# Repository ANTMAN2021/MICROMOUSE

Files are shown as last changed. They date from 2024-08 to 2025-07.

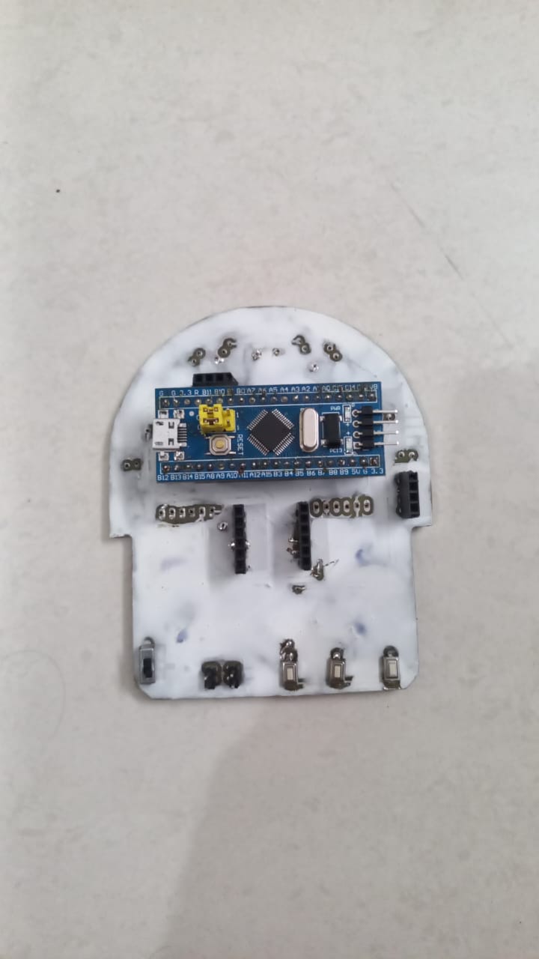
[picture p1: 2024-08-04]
Images/IMG-20240708-WA0024.jpg

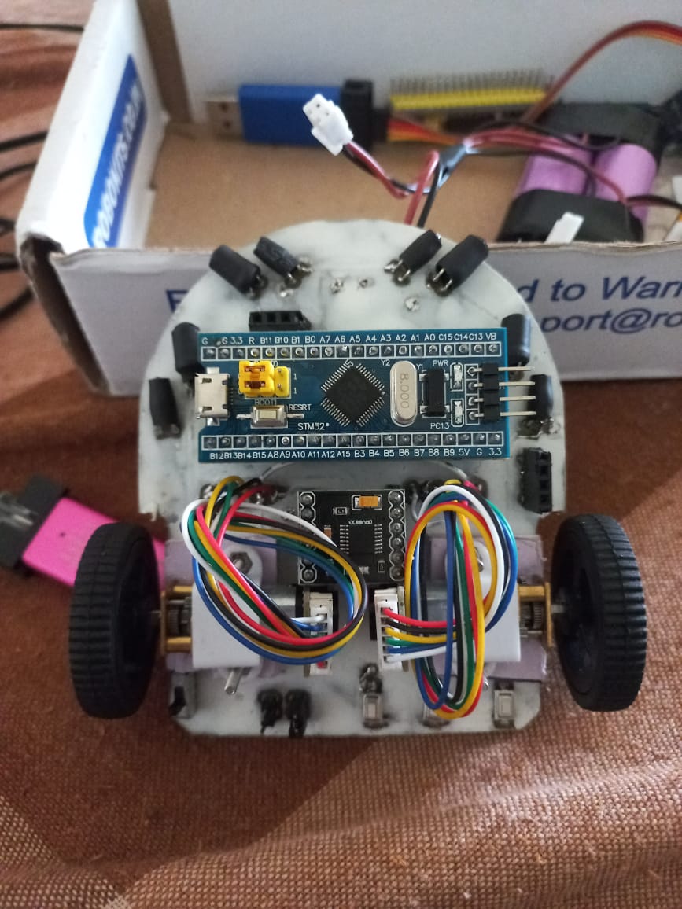
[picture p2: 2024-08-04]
Images/IMG-20240804-WA0022.jpg

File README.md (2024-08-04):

# MICROMOUSE
As a Team Robotics projects, this is a stm32 based micromouse.
There are two pcbs, one based on stm32f103c8t6 and other on stm32f405rgt6.
The assembled bot is on stm32f103 bluepill.
Motor driver used is DRV8833 and sensors are IR sensors.
N20 motors with encoders are used.
Basic running code is given above, shortest path algorithm is in progress.

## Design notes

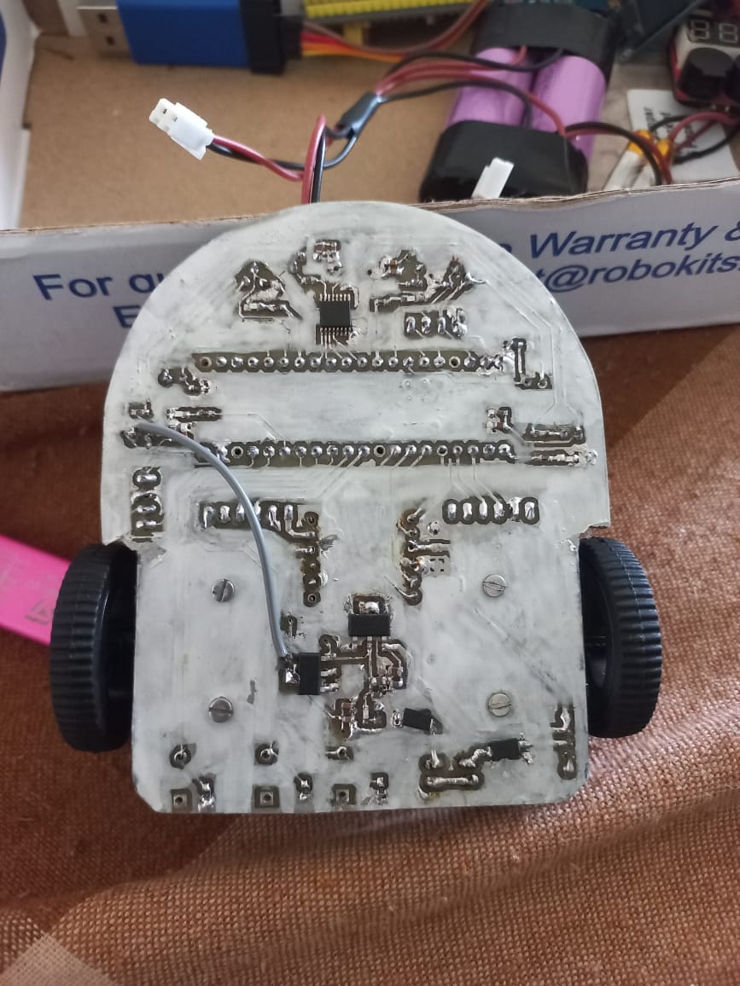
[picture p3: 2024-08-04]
Images/IMG-20240804-WA0023.jpg

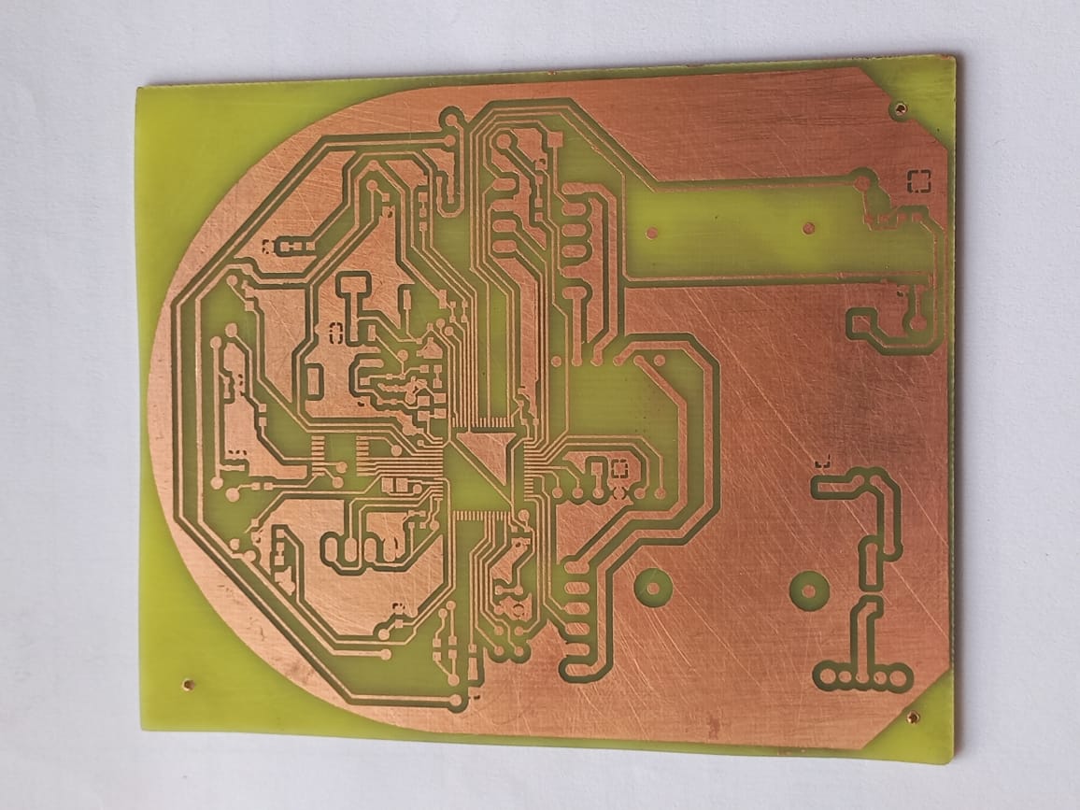
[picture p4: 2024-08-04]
Images/IMG-20240804-WA0025.jpg

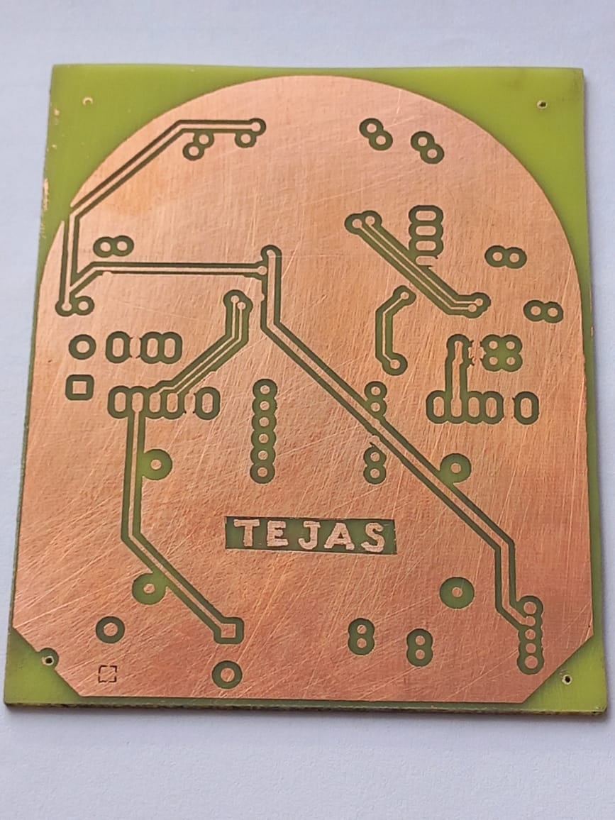
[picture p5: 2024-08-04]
Images/IMG-20240804-WA0026.jpg

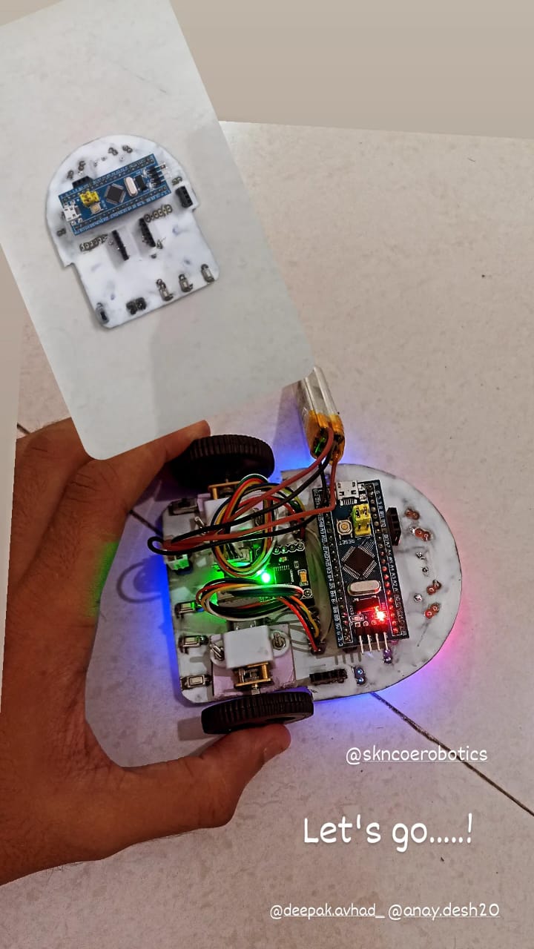
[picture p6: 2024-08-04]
Images/IMG-20240804-WA0024.jpg

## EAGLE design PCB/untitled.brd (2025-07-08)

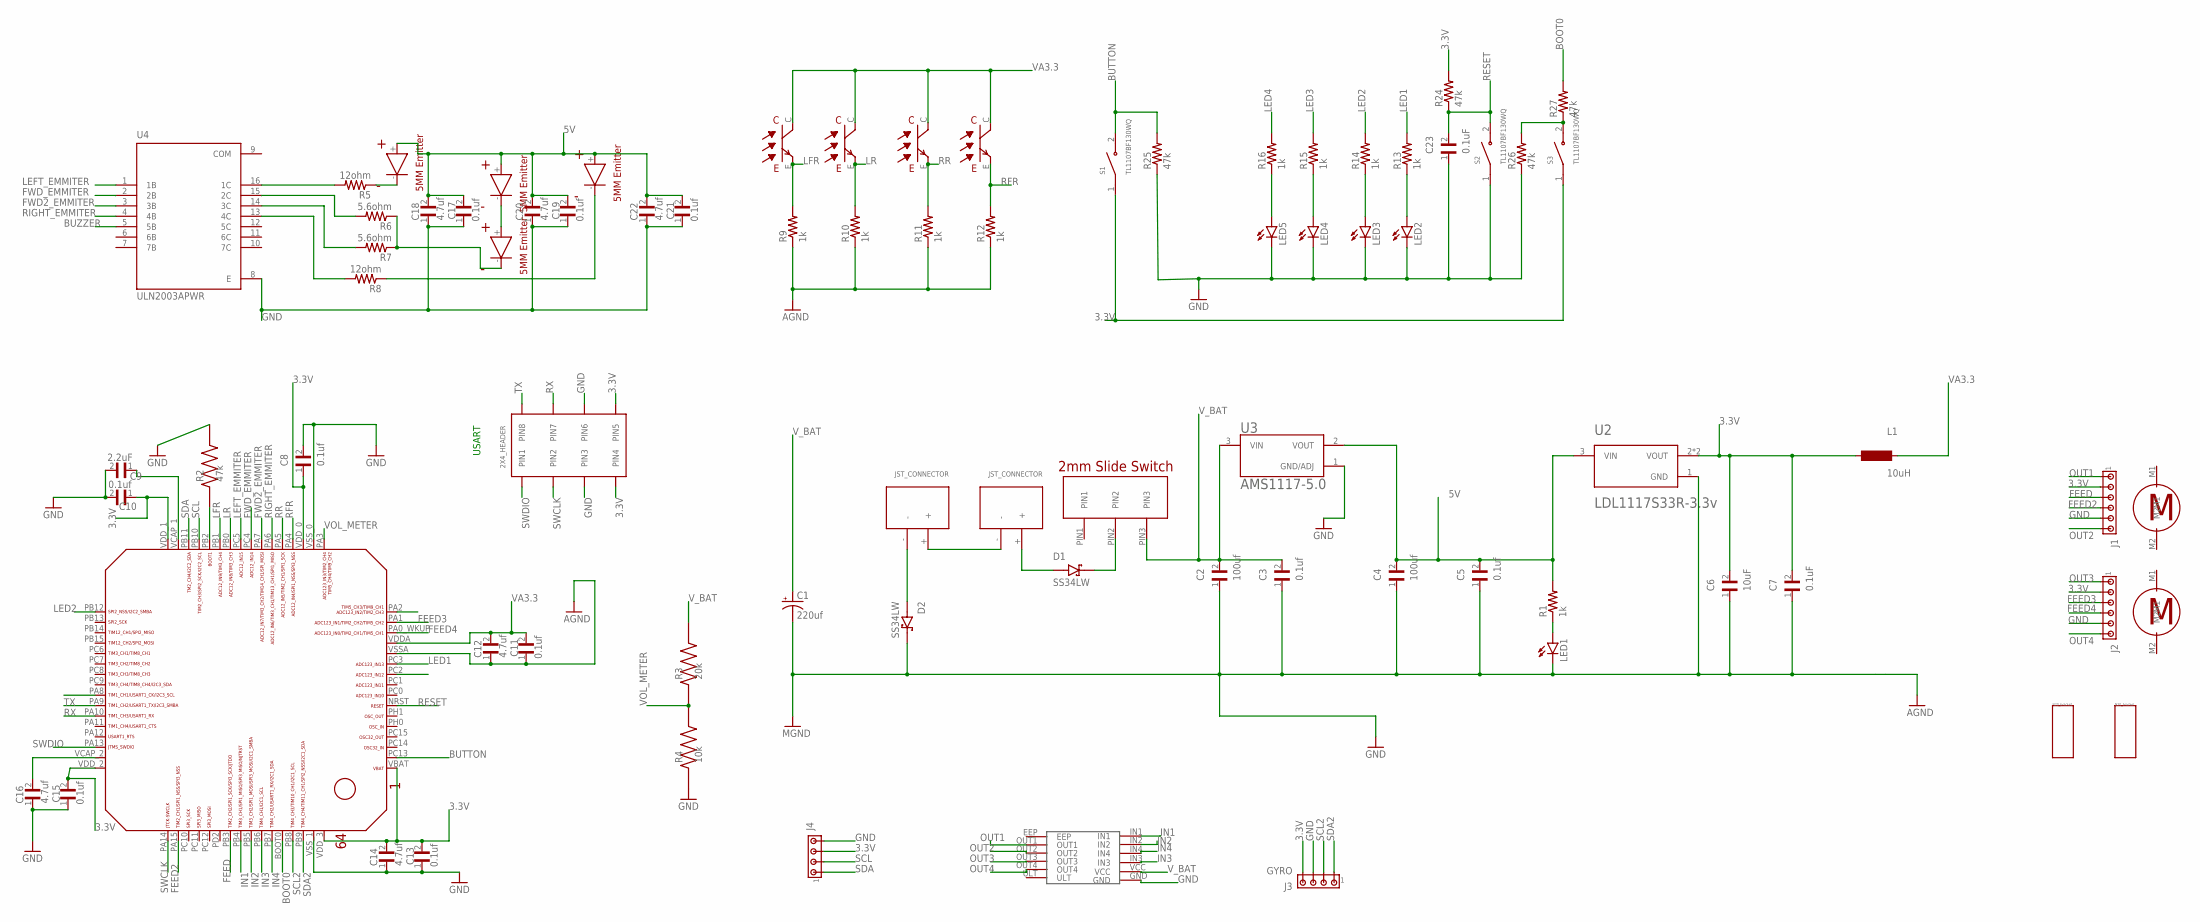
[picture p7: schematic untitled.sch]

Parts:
C1: 220uf; EIA3216
C2, C4: 100uf; CAPC0603X35N
C3, C5, C8, C10, C11, C13, C15, C17, C19, C21: 0.1uf; CAPC0603X35N
C6: 10uF; CAPC0603X35N
C7, C23: 0.1uF; CAPC0603X35N
C9: 2.2uF; CAPC0603X35N
C12, C14, C16, C18, C20, C22: 4.7uf; CAPC0603X35N
D1, D2: SS34LW; SODFL3718X102N
EMMI1: EMITTER
J1, J2: MTA06-100; 10X06MTA
J3: GYRO; 10X04MTA
J4: MTA04-100; 10X04MTA
L1: 10uH; MS42
LED1, LED2, LED3, LED4, LED5: LEDCHIPLED_0805; CHIPLED_0805
R1, R9, R10, R11, R12, R13, R14, R15, R16: 1k; 0603-RES
R2: 47k; RES_ERJU01F3570C
R3: 20k; RES_ERJU01F3570C
R4: 10k; RES_ERJU01F3570C
R5, R8: 12ohm; 0603-RES
R6, R7: 5.6ohm; 0603-RES
R24, R25, R26, R27: 47k; 0603-RES
S1, S2, S3: TL1107BF130WQ; SW_TL1107BF130WQ
STM32F405RGT6: STM32F405/415_LQFP64
U2: LDL1117S33R-3.3v; SOT230P700X180-4N
U3: AMS1117-5.0; SOT229P700X180-4N
U4: ULN2003APWR; SOP65P640X120-16N
U$1, U$4: N20_BRACKET; BRACKER
U$2, U$3: MOTOR_N20
U$5, U$6: JST_CONNECTOR_FEMALE
U$8: 2MMS_SLIDE_SWITCH
U$10: 2X3_HEADER
U$11: DRV8833
U$12, U$16, U$17, U$18: RECEIVER
U$13, U$14, U$15: EMITTER

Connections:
3.3V: C6.2, C7.2, C8.1, C10.1, C13.2, C14.2, C15.2, J1.2, J2.2, J3.4, J4.3, L1.1, R24.2, S1.1, S3.1, STM32F405RGT6.VBAT, STM32F405RGT6.VDD_0, STM32F405RGT6.VDD_1, STM32F405RGT6.VDD_2, STM32F405RGT6.VDD_3, U2.2 (VOUT), U2.4 (VOUT), U$10.PIN4, U$10.PIN5
5V: C4.2, C5.2, C17.2, C18.2, C19.2, C20.2, C21.2, C22.2, EMMI1.+, R1.2, U2.3 (VIN), U3.2 (VOUT), U$13.+, U$15.+
BOOT0: R27.2, STM32F405RGT6.BOOT0
BUTTON: R25.2, S1.2, STM32F405RGT6.PC13
BUZZER: U4.5 (5B)
COM: U4.9 (COM)
FEED: J1.3, STM32F405RGT6.PB3
FEED2: J1.4, STM32F405RGT6.PA15
FEED3: J2.3, STM32F405RGT6.PA1
FEED4: J2.4, STM32F405RGT6.PA0_WKUP (PA0_AKUP)
FWD2_EMMITER: STM32F405RGT6.PA7, U4.3 (3B)
FWD_EMMITER: STM32F405RGT6.PC4, U4.2 (2B)
GND: C1.C (-), C2.1, C3.1, C4.1, C5.1, C6.1, C7.1, C8.2, C9.2, C10.2, C11.1, C12.1, C13.1, C14.1, C15.1, C16.1, C17.1, C18.1, C19.1, C20.1, C21.1, C22.1, C23.1, D2.C (K), J1.5, J2.5, J3.3, J4.4, LED1.C, LED2.C, LED3.C, LED4.C, LED5.C, R2.2, R4.1, R9.1, R10.1, R11.1, R12.1, R25.1, R26.1, S2.1, STM32F405RGT6.VSSA, STM32F405RGT6.VSS_0, STM32F405RGT6.VSS_1, U2.1 (GND), U3.1 (GND/ADJ), U4.8 (E), U$10.PIN3, U$10.PIN6, U$11.GND
IN1: STM32F405RGT6.PB4, U$11.IN1
IN2: STM32F405RGT6.PB5, U$11.IN2
IN3: STM32F405RGT6.PB6, U$11.IN3
IN4: STM32F405RGT6.PB7, U$11.IN4
LED1: R13.2, STM32F405RGT6.PC3
LED2: R14.2, STM32F405RGT6.PB12
LED3: R15.2, STM32F405RGT6.PC2
LED4: R16.2, STM32F405RGT6.PA8
LEFT_EMMITER: STM32F405RGT6.PC5, U4.1 (1B)
LFR: R9.2, STM32F405RGT6.PB1, U$18.E
LR: R10.2, STM32F405RGT6.PB0, U$17.E
unnamed: U$13.-, U$14.+
unnamed: U$5.+, U$6.-
unnamed: R2.1, STM32F405RGT6.PB2
unnamed: D1.C (K), U$8.PIN2
unnamed: R7.2, U4.14 (3C)
unnamed: C9.1, STM32F405RGT6.VCAP_1
unnamed: LED1.A, R1.1
unnamed: C16.2, STM32F405RGT6.VCAP_2
unnamed: LED2.A, R13.1
unnamed: D1.A, U$6.+
unnamed: EMMI1.-, R5.1
unnamed: R5.2, U4.16 (1C)
unnamed: D2.A, U$5.-
unnamed: LED3.A, R14.1
unnamed: R6.2, U4.15 (2C)
unnamed: R6.1, R7.1, U$14.-
unnamed: R8.2, U4.13 (4C)
unnamed: R8.1, U$15.-
unnamed: LED4.A, R15.1
unnamed: R26.2, R27.1, S3.2
unnamed: LED5.A, R16.1
OUT1: J1.1, U$11.OUT1
OUT2: J1.6, U$11.OUT2
OUT3: J2.1, U$11.OUT3
OUT4: J2.6, U$11.OUT4
RESET: C23.2, R24.1, S2.2, STM32F405RGT6.NRST
RFR: R12.2, STM32F405RGT6.PA4, U$12.E
RIGHT_EMMITER: STM32F405RGT6.PA6, U4.4 (4B)
RR: R11.2, STM32F405RGT6.PA5, U$16.E
RX: STM32F405RGT6.PA10, U$10.PIN7
SCL: J4.2, STM32F405RGT6.PB10
SCL2: J3.2, STM32F405RGT6.PB8
SDA: J4.1, STM32F405RGT6.PB11
SDA2: J3.1, STM32F405RGT6.PB9
SWCLK: STM32F405RGT6.PA14, U$10.PIN2
SWDIO: STM32F405RGT6.PA13, U$10.PIN1
TX: STM32F405RGT6.PA9, U$10.PIN8
VA3.3: C11.2, C12.2, L1.2, STM32F405RGT6.VDDA, U$12.C, U$16.C, U$17.C, U$18.C
VOL_METER: R3.1, R4.2, STM32F405RGT6.PA3
V_BAT: C1.A (+), C2.2, C3.2, R3.2, U3.3 (VIN), U$8.PIN3, U$11.VCC

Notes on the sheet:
USART

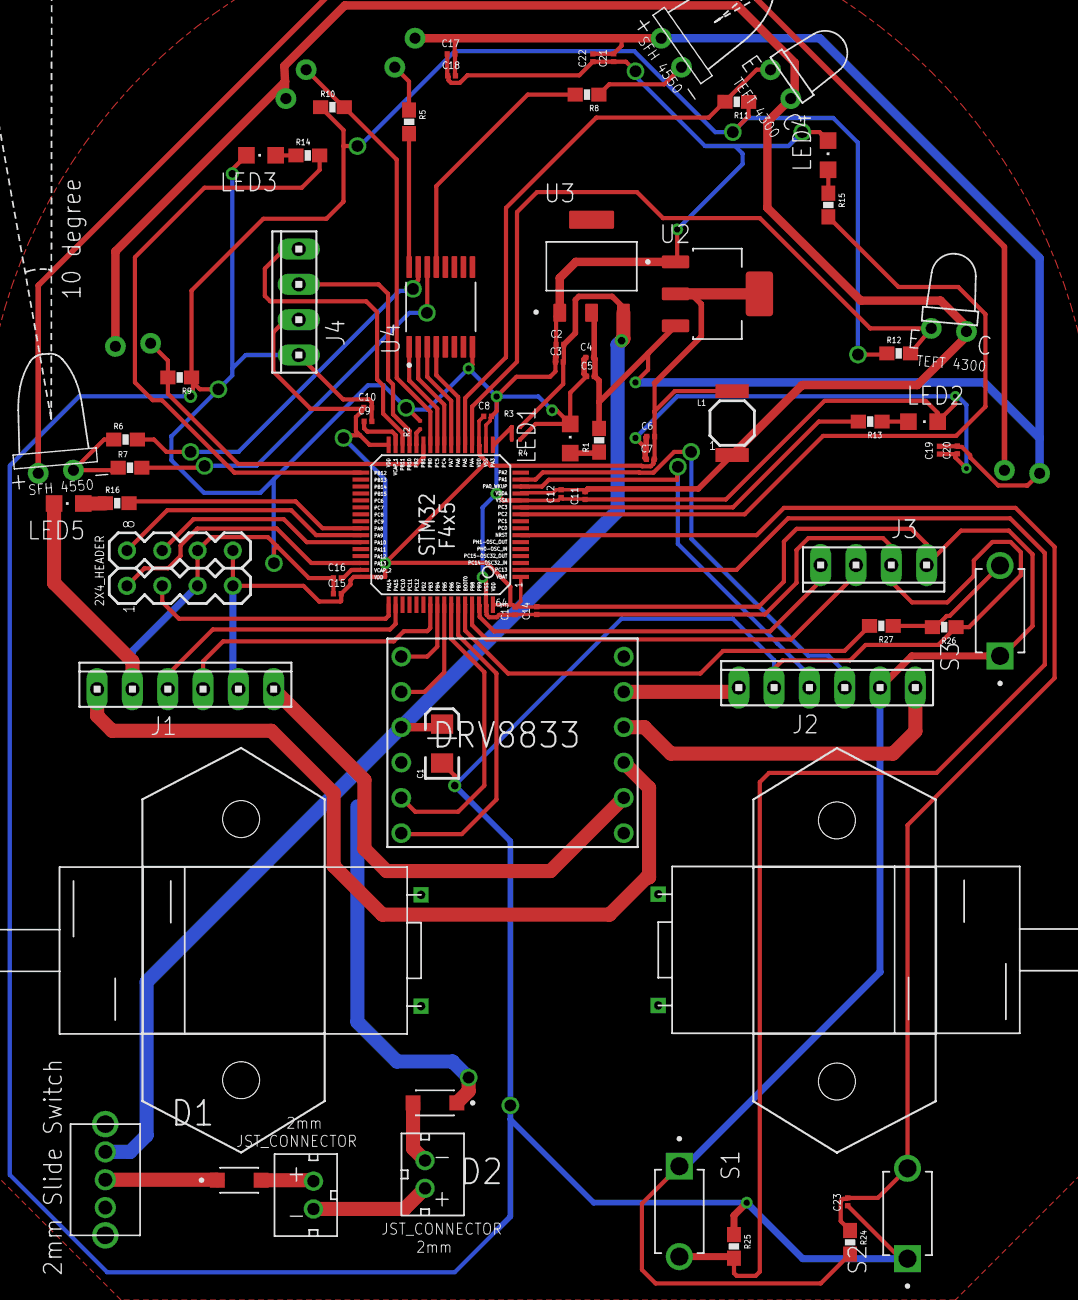
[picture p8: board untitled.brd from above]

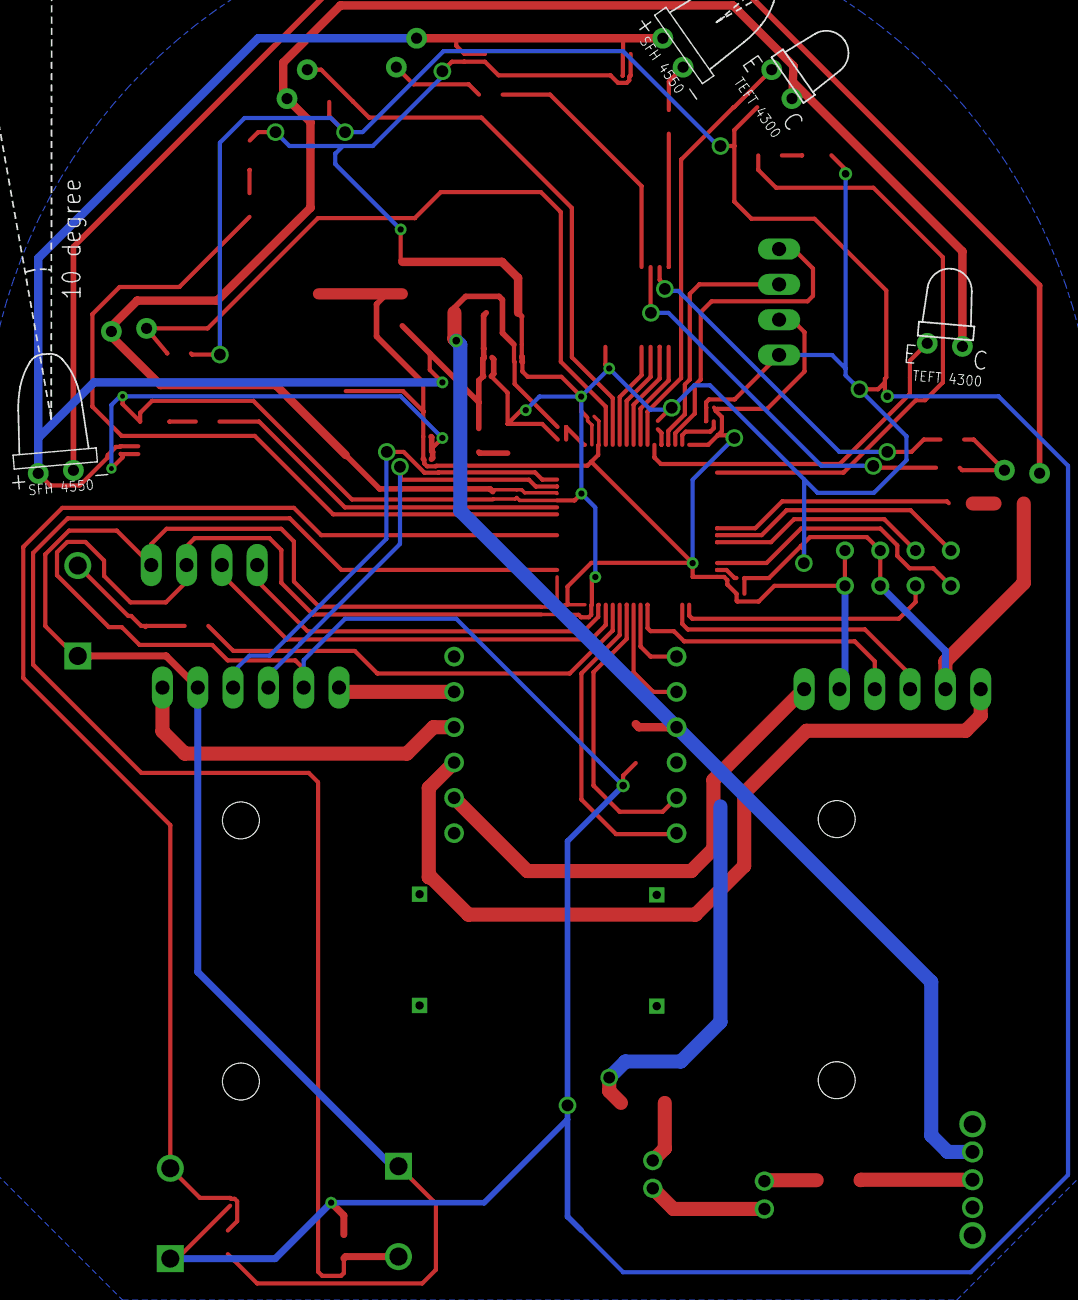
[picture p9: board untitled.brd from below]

Board: 2 copper layers, 79 parts (4 on the bottom side), 62 nets.

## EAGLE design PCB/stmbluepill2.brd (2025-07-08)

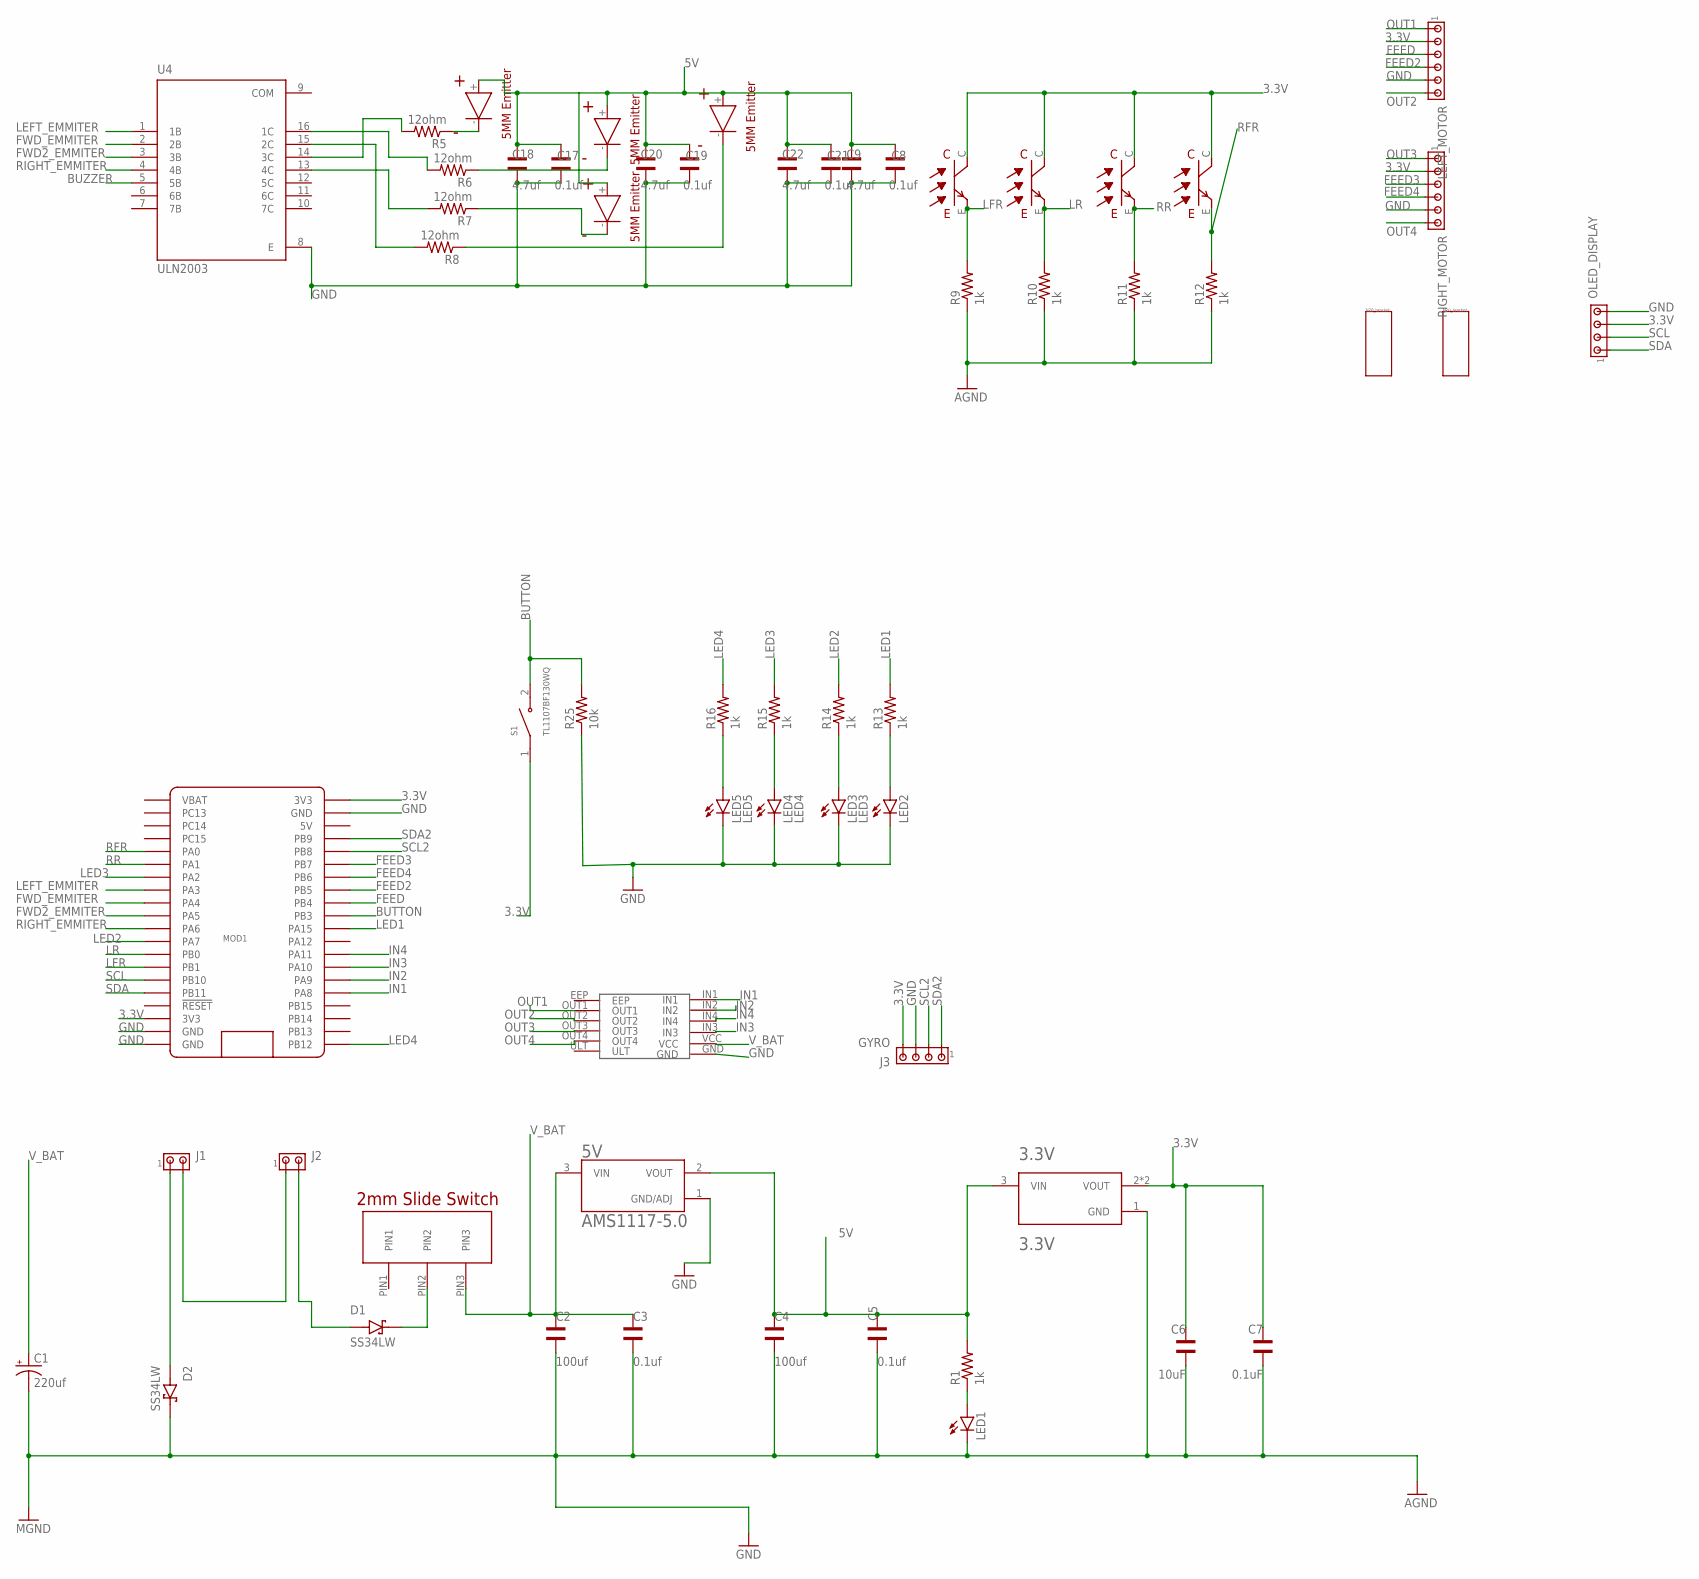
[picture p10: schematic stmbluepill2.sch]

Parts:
3.3V: 3.3V; SOT230P700X180-4N
5V: AMS1117-5.0; SOT229P700X180-4N
C1: 220uf; EIA3216
C2, C4: 100uf; WCAP-CSGP_885012206026
C3, C5, C8, C17, C19, C21: 0.1uf; WCAP-CSGP_885012206026
C6: 10uF; WCAP-CSGP_885012206026
C7: 0.1uF; WCAP-CSGP_885012206026
C9, C18, C20, C22: 4.7uf; WCAP-CSGP_885012206026
D1, D2: SS34LW; SODFL3718X102N
EMMI1: EMITTER
J1, J2: MTA02-100; 10X02MTA
J3: GYRO; 10X04MTA
LED1, LED2: LEDCHIPLED_0805; CHIPLED_0805
LED3: LED3; CHIPLED_0805
LED4: LED4; CHIPLED_0805
LED5: LED5; CHIPLED_0805
LEFT_MOTOR: MTA06-100; 10X06MTA
MOD1: BLUE_PILLADVANCED; BLUE_PILL_ADV
OLED_DISPLAY: MTA04-100; 10X04MTA
R1, R9, R10, R11, R12, R13, R14, R15, R16: 1k; 0603-RES
R5, R6, R7, R8: 12ohm; 0603-RES
R25: 10k; 0603-RES
RIGHT_MOTOR: MTA06-100; 10X06MTA
S1: TL1107BF130WQ; SW_TL1107BF130WQ
U4: ULN2003; SOP65P640X120-16N
U$1, U$4: N20_BRACKET; BRACKER
U$8: 2MMS_SLIDE_SWITCH
U$11: DRV8833
U$12, U$16, U$17, U$18: RECEIVER
U$13, U$14, U$15: EMITTER

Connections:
3.3V: 3.3V.2 (VOUT), 3.3V.4 (VOUT), C6.2, C7.2, J3.4, LEFT_MOTOR.2, MOD1.P$20 (3V3), MOD1.P$23 (3V3), OLED_DISPLAY.3, RIGHT_MOTOR.2, S1.1, U$12.C, U$16.C, U$17.C, U$18.C
5V: 3.3V.3 (VIN), 5V.2 (VOUT), C4.2, C5.2, C8.2, C9.2, C17.2, C18.2, C19.2, C20.2, C21.2, C22.2, EMMI1.+, R1.2, U$13.+, U$14.+, U$15.+
BUTTON: MOD1.P$11 (PB3), R25.2, S1.2
BUZZER: U4.5 (5B)
COM: U4.9 (COM)
FEED: LEFT_MOTOR.3, MOD1.P$12 (PB4)
FEED2: LEFT_MOTOR.4, MOD1.P$13 (PB5)
FEED3: MOD1.P$15 (PB7), RIGHT_MOTOR.3
FEED4: MOD1.P$14 (PB6), RIGHT_MOTOR.4
FWD2_EMMITER: MOD1.P$31 (PA5), U4.3 (3B)
FWD_EMMITER: MOD1.P$32 (PA4), U4.2 (2B)
GND: 3.3V.1 (GND), 5V.1 (GND/ADJ), C1.C (-), C2.1, C3.1, C4.1, C5.1, C6.1, C7.1, C8.1, C9.1, C17.1, C18.1, C19.1, C20.1, C21.1, C22.1, D2.C (K), J3.3, LED1.C, LED2.C, LED3.C, LED4.C, LED5.C, LEFT_MOTOR.5, MOD1.P$19 (GND), MOD1.P$21 (GND), MOD1.P$22 (GND), OLED_DISPLAY.4, R9.1, R10.1, R11.1, R12.1, R25.1, RIGHT_MOTOR.5, U4.8 (E), U$11.GND
IN1: MOD1.P$5 (PA8), U$11.IN1
IN2: MOD1.P$6 (PA9), U$11.IN2
IN3: MOD1.P$7 (PA10), U$11.IN3
IN4: MOD1.P$8 (PA11), U$11.IN4
LED1: MOD1.P$10 (PA15), R13.2
LED2: MOD1.P$29 (PA7), R14.2
LED3: MOD1.P$34 (PA2), R15.2
LED4: MOD1.P$1 (PB12), R16.2
LEFT_EMMITER: MOD1.P$33 (PA3), U4.1 (1B)
LFR: MOD1.P$27 (PB1), R9.2, U$18.E
LR: MOD1.P$28 (PB0), R10.2, U$17.E
unnamed: R6.1, U$13.-
unnamed: J1.2, J2.1
unnamed: D1.C (K), U$8.PIN2
unnamed: R7.2, U4.13 (4C)
unnamed: R5.2, U4.14 (3C)
unnamed: LED1.A, R1.1
unnamed: R6.2, U4.16 (1C)
unnamed: LED2.A, R13.1
unnamed: D1.A, J2.2
unnamed: EMMI1.-, R5.1
unnamed: D2.A, J1.1
unnamed: LED3.A, R14.1
unnamed: R7.1, U$14.-
unnamed: R8.2, U4.15 (2C)
unnamed: R8.1, U$15.-
unnamed: LED4.A, R15.1
unnamed: LED5.A, R16.1
OUT1: LEFT_MOTOR.1, U$11.OUT1
OUT2: LEFT_MOTOR.6, U$11.OUT2
OUT3: RIGHT_MOTOR.1, U$11.OUT3
OUT4: RIGHT_MOTOR.6, U$11.OUT4
RFR: MOD1.P$36 (PA0), R12.2, U$12.E
RIGHT_EMMITER: MOD1.P$30 (PA6), U4.4 (4B)
RR: MOD1.P$35 (PA1), R11.2, U$16.E
SCL: MOD1.P$26 (PB10), OLED_DISPLAY.2
SCL2: J3.2, MOD1.P$16 (PB8)
SDA: MOD1.P$25 (PB11), OLED_DISPLAY.1
SDA2: J3.1, MOD1.P$17 (PB9)
V_BAT: 5V.3 (VIN), C1.A (+), C2.2, C3.2, U$8.PIN3, U$11.VCC

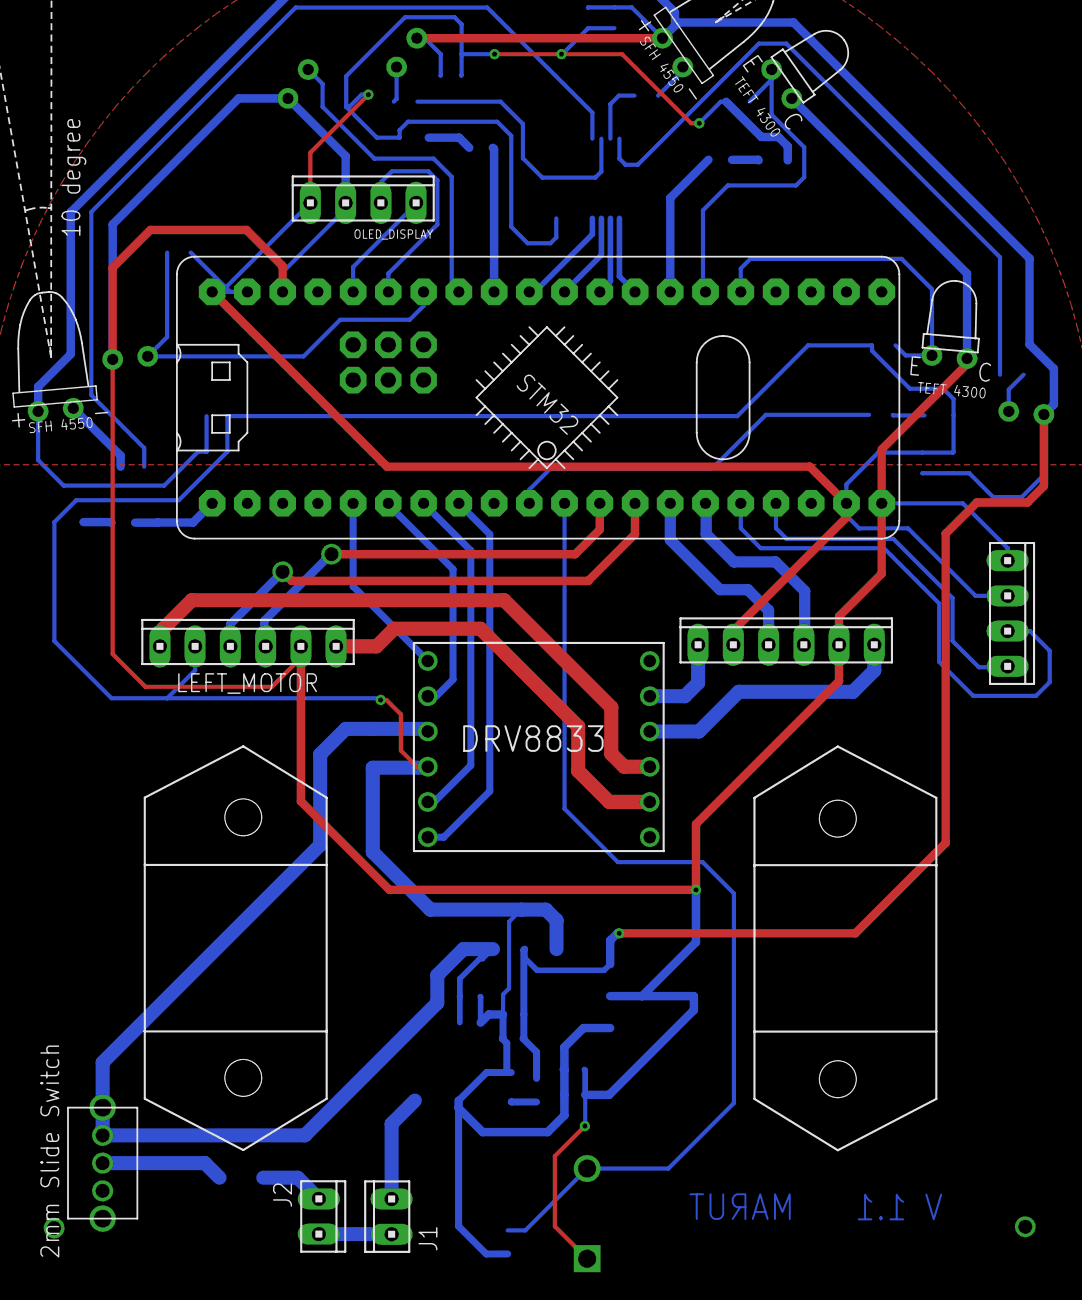
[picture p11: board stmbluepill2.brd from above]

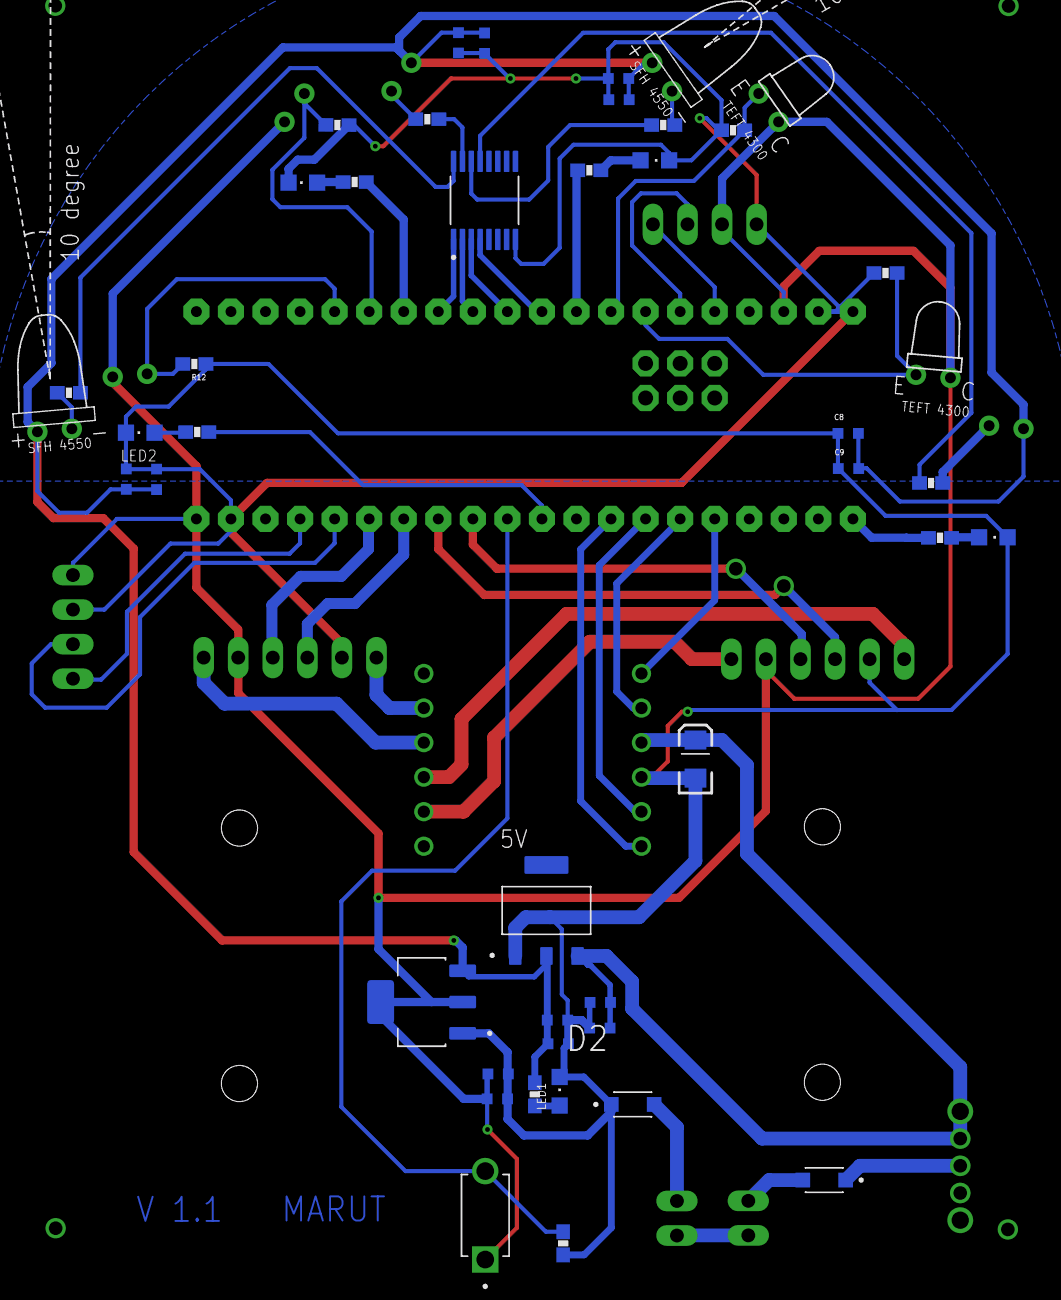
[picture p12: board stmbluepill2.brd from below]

Board: 2 copper layers, 59 parts (44 on the bottom side), 50 nets.

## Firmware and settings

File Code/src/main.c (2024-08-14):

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
/* Includes ------------------------------------------------------------------*/
#include "main.h"

/* USER CODE BEGIN Includes */
#include <string.h>
#include <stdio.h>
/* USER CODE END Includes */

ADC_HandleTypeDef hadc1;
DMA_HandleTypeDef hdma_adc1;

TIM_HandleTypeDef htim1;

UART_HandleTypeDef huart3;

void SystemClock_Config(void);
static void MX_GPIO_Init(void);
static void MX_DMA_Init(void);
static void MX_USART3_UART_Init(void);
static void MX_ADC1_Init(void);
static void MX_TIM1_Init(void);
/* USER CODE BEGIN 0 */

uint32_t AD_RES_BUFFER[4];

uint32_t IR1;
uint32_t IR2;
uint32_t IR3;
uint32_t IR4;
int previousError, PIDvalue, error, front;
int P;
int D;
int I ;
int lsp, rsp;
int lfspeed = 250;

uint32_t Kp = 6.5  ;
uint32_t Kd = 5 ;
uint32_t Ki = 0 ;
/* USER CODE END 0 */

/**
  * @brief  The application entry point.
  * @retval int
  */
int main(void)
{
  /* MCU Configuration--------------------------------------------------------*/

  /* Reset of all peripherals, Initializes the Flash interface and the Systick. */

	HAL_Init();

  /* Configure the system clock */
  SystemClock_Config();

  /* Initialize all configured peripherals */
  MX_GPIO_Init();
  MX_DMA_Init();
  MX_USART3_UART_Init();
  MX_ADC1_Init();
  MX_TIM1_Init();
  /* USER CODE BEGIN 2 */

  //this pointer will also be used to read the analog value,

  /* USER CODE END 2 */

  /* Infinite loop */
  /* USER CODE BEGIN WHILE */
  HAL_GPIO_WritePin(GPIOA,
    		  l_emi_Pin |
    		  f_emi_Pin|
    		  f2_emi_Pin|
            r_emi_Pin
    		  , GPIO_PIN_SET);

        /* Infinite loop */
        /* USER CODE BEGIN WHILE */
        while (1)
        {
        /* USER CODE END WHILE */
        	HAL_ADC_Start_DMA(&hadc1, AD_RES_BUFFER, 4);
        	HAL_ADC_Stop_DMA(&hadc1);
        	HAL_ADCEx_Calibration_Start(&hadc1);

        	HAL_ADC_Start_DMA(&hadc1, AD_RES_BUFFER, 4);
        	        HAL_Delay(1);

        	if (HAL_DMA_STATE_BUSY != hdma_adc1.State) {
    			IR1=AD_RES_BUFFER[0];
    			IR2=AD_RES_BUFFER[1];
    			IR3=AD_RES_BUFFER[2];
    			IR4=AD_RES_BUFFER[3];
        	}

     	front=(AD_RES_BUFFER[0] + AD_RES_BUFFER[3])/2;

	        error = (AD_RES_BUFFER[1] - AD_RES_BUFFER[2]);
 	        P = error;
 	       // I = I + error;
 	        D = error - previousError;
 	        PIDvalue = (Kp * P) +  (Kd * D);
 	        previousError = error;
 	        lsp = lfspeed - PIDvalue;
 	        rsp = lfspeed + PIDvalue;
 	        if (lsp > 255) {
 	        lsp = 255;
 	        }
 	        if (lsp < 0) {
 	        lsp = 0;
 	        }
 	        if (rsp > 255) {
 	        rsp = 255;
 	        }
 	        if (rsp < 0) {
 	        rsp = 0;
 	        }
     
  /* USER CODE END 3 */
}

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


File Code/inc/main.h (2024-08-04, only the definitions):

#define led3_Pin GPIO_PIN_2
#define led3_GPIO_Port GPIOA
#define l_emi_Pin GPIO_PIN_3
#define l_emi_GPIO_Port GPIOA
#define f_emi_Pin GPIO_PIN_4
#define f_emi_GPIO_Port GPIOA
#define f2_emi_Pin GPIO_PIN_5
#define f2_emi_GPIO_Port GPIOA
#define r_emi_Pin GPIO_PIN_6
#define r_emi_GPIO_Port GPIOA
#define led2_Pin GPIO_PIN_7
#define led2_GPIO_Port GPIOA
#define led4_Pin GPIO_PIN_12
#define led4_GPIO_Port GPIOB
#define led1_Pin GPIO_PIN_7
#define led1_GPIO_Port GPIOB

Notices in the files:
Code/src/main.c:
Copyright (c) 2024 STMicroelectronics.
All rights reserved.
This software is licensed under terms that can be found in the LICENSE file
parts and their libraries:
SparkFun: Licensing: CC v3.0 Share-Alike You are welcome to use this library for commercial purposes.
